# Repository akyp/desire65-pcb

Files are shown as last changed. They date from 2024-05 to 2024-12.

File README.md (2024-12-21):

# desire65-pcb
 
 Open-source 65% hotswap pcb. Could be useful for keyboard designers looking for a PCB for gasket or top-mounted boards.
  
 ## Features
 
 - [UDB (Unified DB)](https://unified-daughterboard.github.io) compatibility (JST-SH variant)
 - Hotswap
 - Underglow RGB LEDs
 - Header for in-switch Caps Lock LED (alternative firmware to use it as backlight to be provided)
 - RP2040 MCU
 - QMK/VIA/Vial firmware
 - Holes under 2u stabilizers to facilitate proper keycap installation on long-pole switches
 - Rounded tracks
 - [STEP file](./step/desire65-rounded.step) provided with all the components visible
 - Requires KiCad 8 to modify or produce production files
 - Font used: [Orbitron](https://fonts.google.com/specimen/Orbitron)
 
## Firmware
 - [QMK](https://config.qmk.fm/#/archerkeyboard/desire65/LAYOUT_65_ansi_blocker_tsangan_split_bs)
 - [VIA](https://www.caniusevia.com/docs/download_firmware)
 - [VIAL (with the Caps Lock footprint configured as QMK Backlighting instead)](https://github.com/akyp/desire65-pcb/releases/tag/v1.0_vial_bl)

## Supported Layout
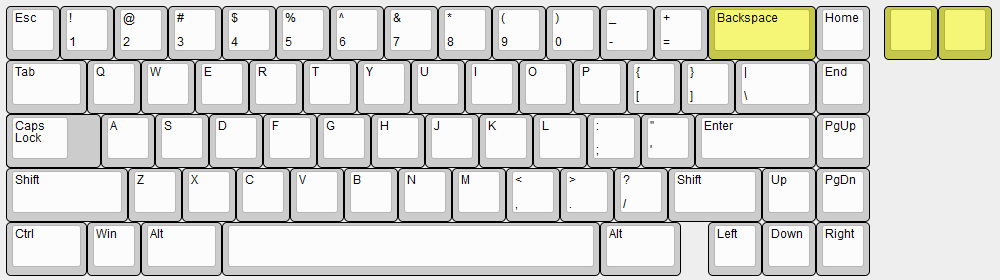
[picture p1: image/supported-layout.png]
Supported Layout


## Renders
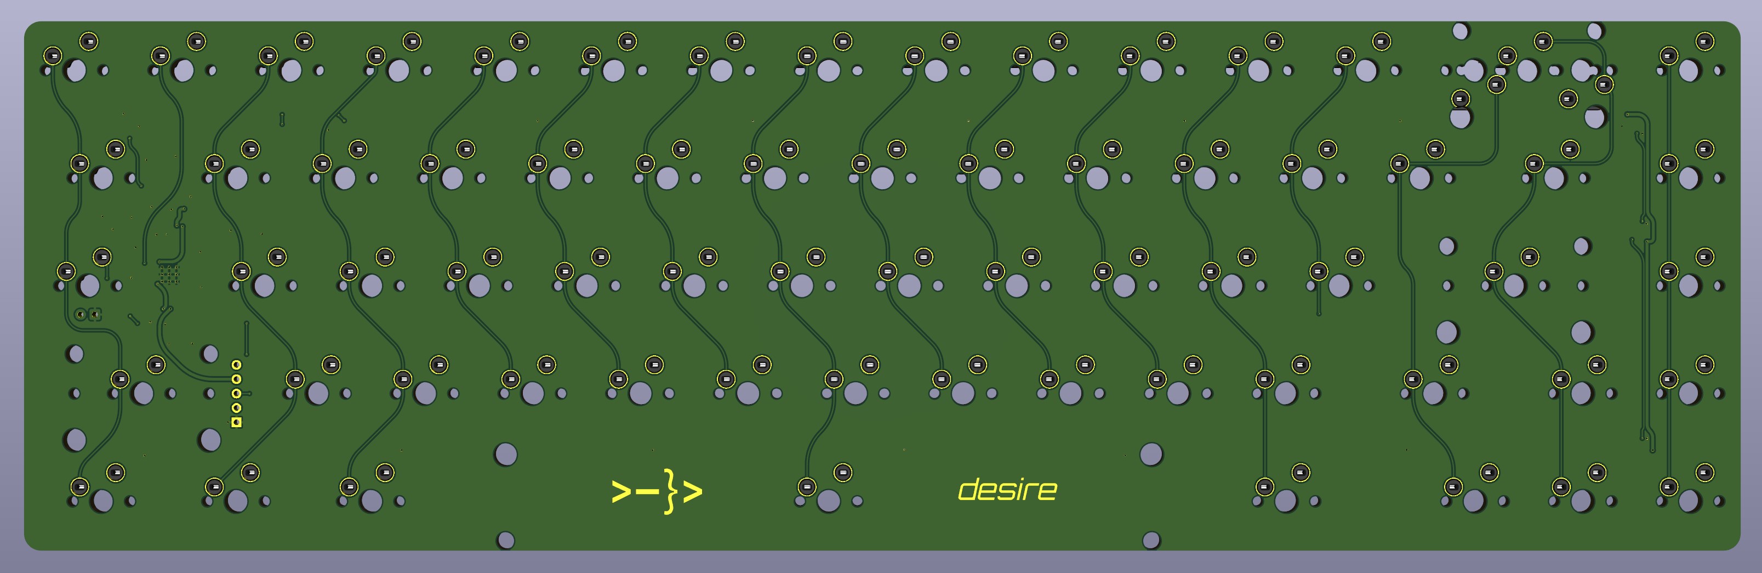
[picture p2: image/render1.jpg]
Render 1

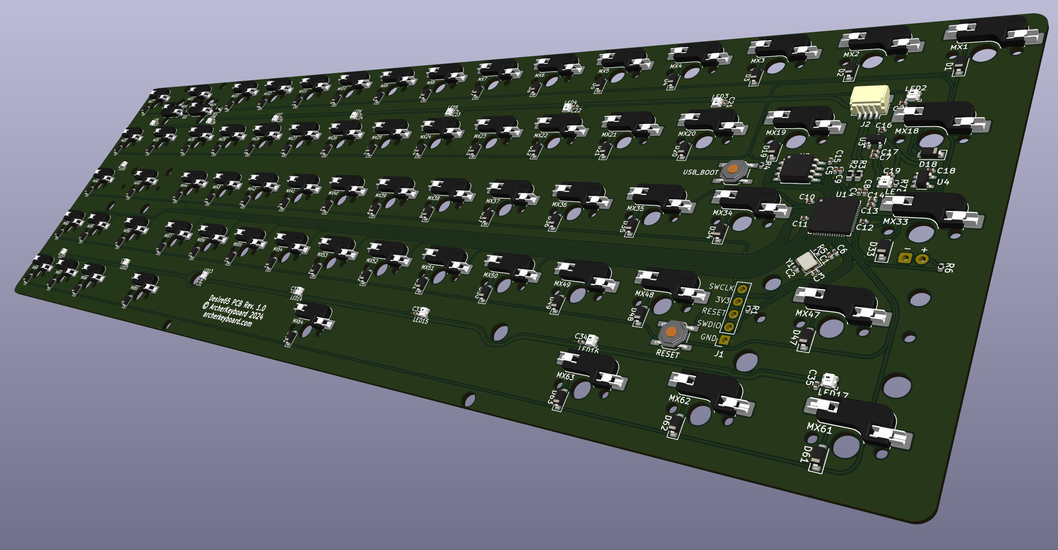
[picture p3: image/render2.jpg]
Render 2


## Prototype Photos
1.2mm PCB produced by JLCPCB
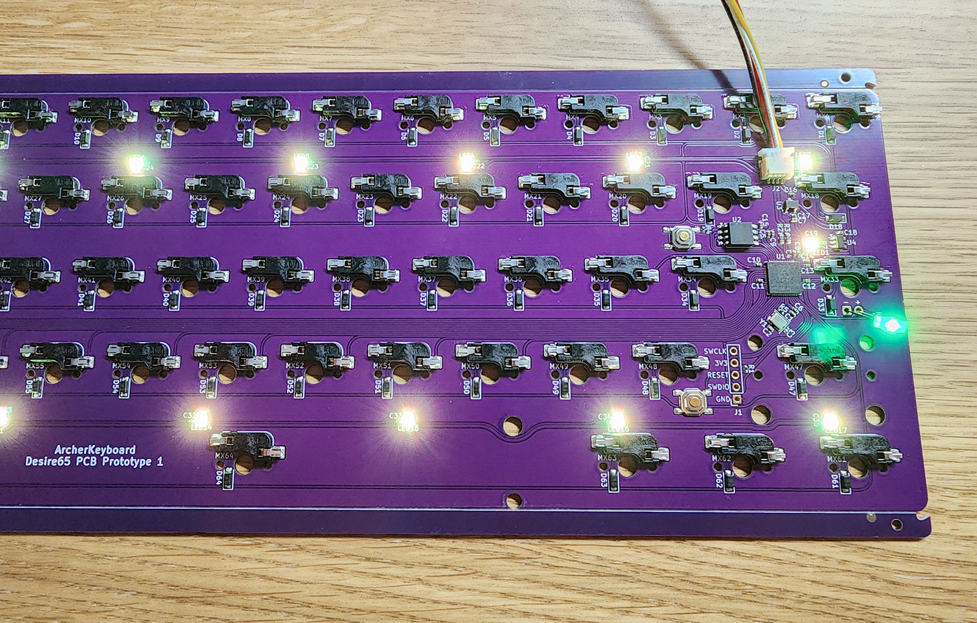
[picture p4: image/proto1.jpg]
Prototype Photo 1

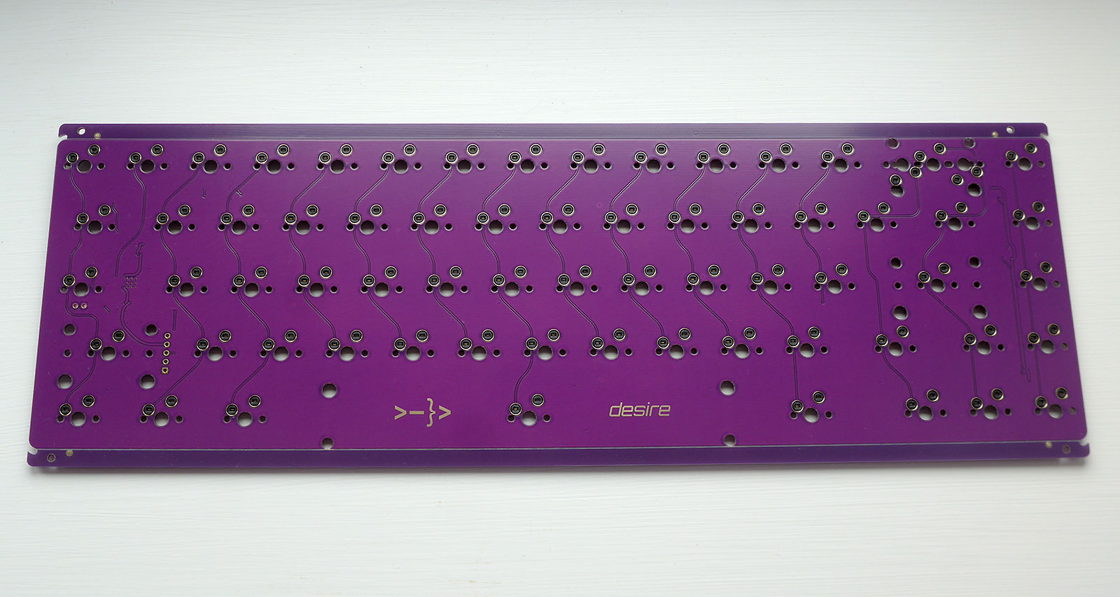
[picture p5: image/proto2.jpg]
Prototype Photo 2

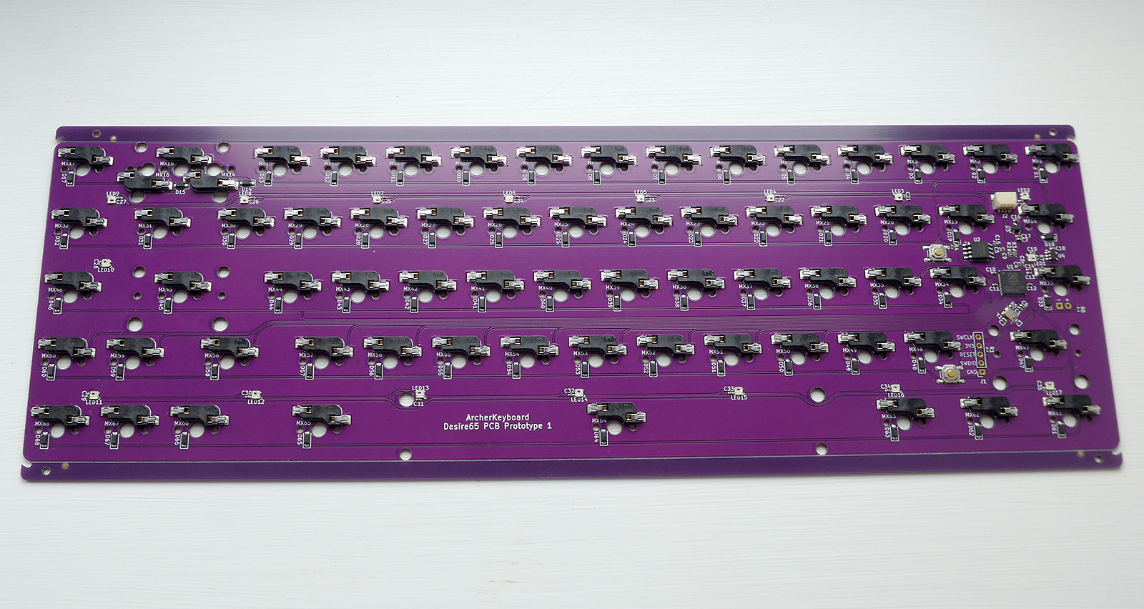
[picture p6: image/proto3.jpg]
Prototype Photo 3


## About the holes under 2u stabilizers
It is not easy to fully install a 2/2.25/2.75u keycap on the stabilizer stems when using a long-pole switch with reduced travel. Often one side will be inserted more than the other, causing rattle. The holes on the PCB allow the use of a spare 2u wire underneath to facilitate pushing the stabilizer stems fully into the keycap.
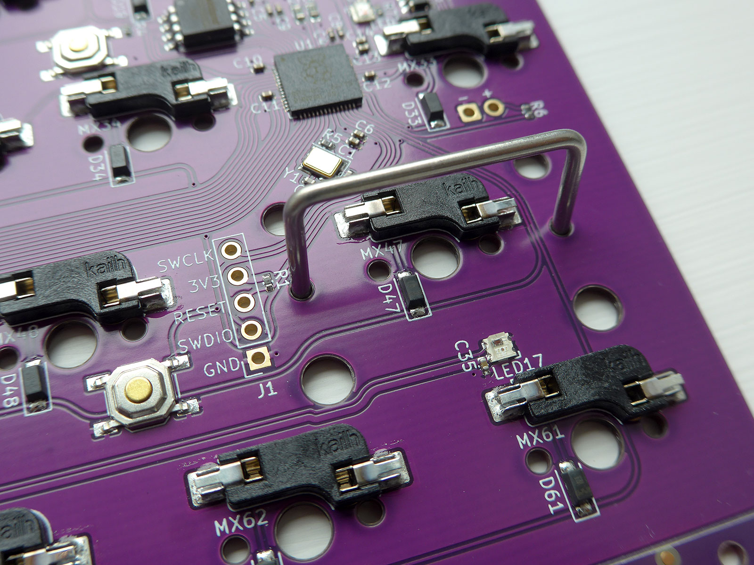
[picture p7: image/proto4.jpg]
Prototype Photo 4


## Plugins Used

 - [marbastlib](https://github.com/ebastler/marbastlib)
 - [Round Tracks](https://github.com/mitxela/kicad-round-tracks)

## If you want to modify the PCB

 - Fork this repo
 - Changes to component placement and tracks must be made to **desire65.kicad_pcb** rather than **desire65-rounded.kicad_pcb**
 - When you're done, use the Round Tracks plugin with **create a new file option** checked to generate a new **desire65-rounded.kicad_pcb**
 - Open it and manually fix track-to-track and track-to-pad clearances. Use DRC to find them.
 - Feel free to ignore the generated **desire65-rounded.kicad_pro**

## Thanks to

 - **Sleepdealr** for the [RP2040 Design Guide](https://github.com/Sleepdealr/RP2040-designguide)
 - **ebastler** for the super-useful [marbastlib](https://github.com/ebastler/marbastlib)
 - **zykrah** for [KiCad KLE Placer](https://github.com/zykrah/kicad-kle-placer) and [Firmware Scripts](https://github.com/zykrah/firmware-scripts)
 - **ai03** for the [PCB Designer Guide](https://wiki.ai03.com/books/pcb-design/chapter/pcb-designer-guide)
 - Folks on Keyboard Atelier Discord

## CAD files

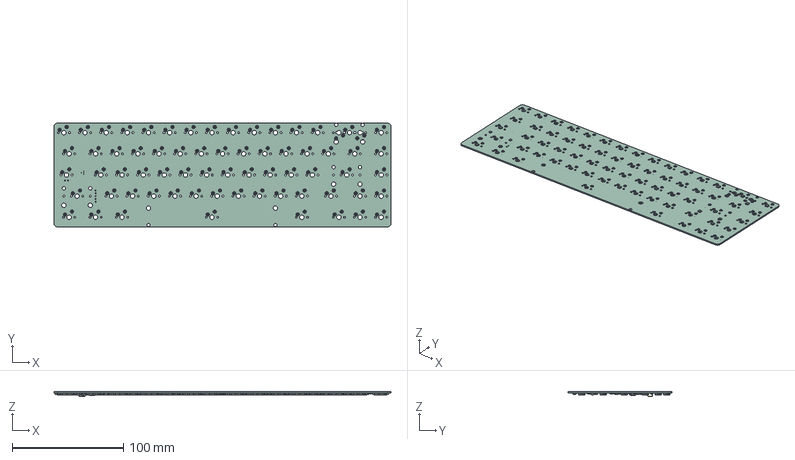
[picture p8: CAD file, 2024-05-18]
step/desire65-rounded.step
303.5 x 93.5 x 4.21 mm
D_SOD_123 x 67
Kailh Hotswap RightVersion v23 x 68
C_0402_1005Metric x 35
Crystal_SMD_3225-4Pin_3.2x2.5mm
SW_SPST_TL3342 x 2
LED_WS2812_2020 v3 x 17
R_0402_1005Metric x 5
R_0603_1608Metric x 2
SOT_23
SOT_23_5
SM04B-SRSS-TB(LF)(SN)
QFN-56-1EP_7x7mm_Pitch0.4mm
SOIC_8_5275x5275mm_P127mm
_autosave-desire65-rounded_PCB

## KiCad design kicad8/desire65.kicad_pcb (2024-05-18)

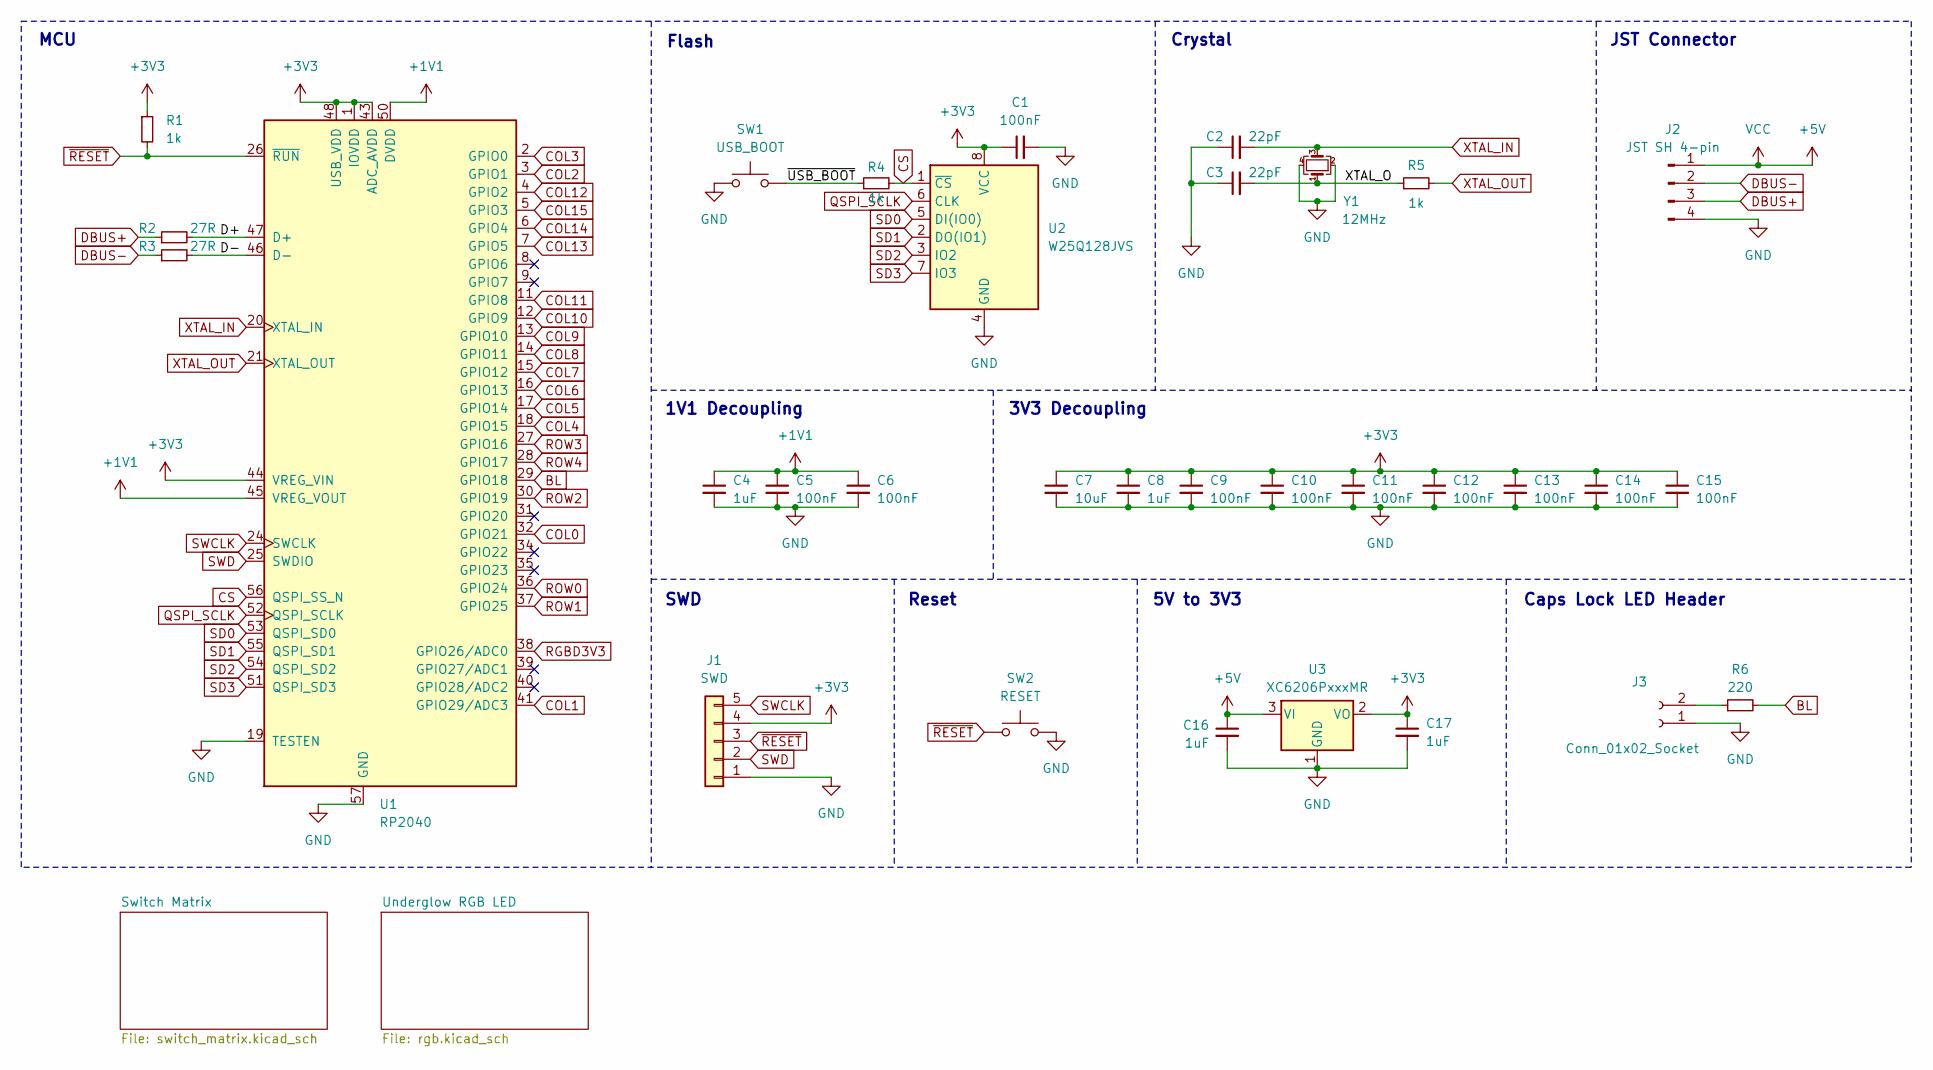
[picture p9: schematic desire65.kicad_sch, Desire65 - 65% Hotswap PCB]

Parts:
C1, C5, C6, C9, C10, C11, C12, C13, C14, C15: 100nF; C_0402_1005Metric; LCSC Part C1525
C2, C3: 22pF; C_0402_1005Metric; LCSC Part C1555
C4, C8, C16, C17: 1uF; C_0402_1005Metric; LCSC Part C52923
C7: 10uF; C_0402_1005Metric; LCSC Part C15525
J1: SWD; PinSocket_1x05_P2.54mm_Vertical; JLCPCB BOM 0
J2: JST SH 4-pin; JST_SH_SM04B-SRSS-TB_1x04-1MP_P1.00mm_Horizontal; LCSC Part C371571
J3: Conn_01x02_Socket; LED_MX_3mm; JLCPCB BOM 0
R1, R4, R5: 1k; R_0402_1005Metric; LCSC Part C11702
R2, R3: 27R; R_0603_1608Metric; LCSC Part C25190
R6: 220; R_0402_1005Metric; LCSC Part C25091
SW1: USB_BOOT; SW_SPST_TL3342
SW2: RESET; SW_SPST_TL3342
U1: RP2040; RP2040-QFN-56; LCSC Part C2040
U2: W25Q128JVS; SOIC-8_5.23x5.23mm_P1.27mm; LCSC Part C97521
U3: XC6206PxxxMR; SOT-23; LCSC Part C5446
Y1: 12MHz; Crystal_SMD_3225-4Pin_3.2x2.5mm; LCSC Part C9002

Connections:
+1V1: C4.1, C5.1, C6.1, U1.23 (DVDD), U1.45 (VREG_VOUT), U1.50 (DVDD)
+3V3: C1.1, C7.1, C8.1, C9.1, C10.1, C11.1, C12.1, C13.1, C14.1, C15.1, C17.1, J1.4, R1.1, U1.1 (IOVDD), U1.10 (IOVDD), U1.22 (IOVDD), U1.33 (IOVDD), U1.42 (IOVDD), U1.43 (ADC_AVDD), U1.44 (VREG_VIN), U1.48 (USB_VDD), U1.49 (IOVDD), U2.8 (VCC), U3.2 (VO)
+5V: C16.1, J2.1, U3.3 (VI); also elsewhere on the board
/D+: R2.2, U1.47 (D+)
/D-: R3.2, U1.46 (D-)
/XTAL_O: C3.2, R5.1, Y1.1
/~USB_BOOT: R4.1, SW1.2
BL: R6.2, U1.29 (GPIO18)
COL0: U1.32 (GPIO21); also elsewhere on the board
COL1: U1.41 (GPIO29/ADC3); also elsewhere on the board
COL2: U1.3 (GPIO1); also elsewhere on the board
COL3: U1.2 (GPIO0); also elsewhere on the board
COL4: U1.18 (GPIO15); also elsewhere on the board
COL5: U1.17 (GPIO14); also elsewhere on the board
COL6: U1.16 (GPIO13); also elsewhere on the board
COL7: U1.15 (GPIO12); also elsewhere on the board
COL8: U1.14 (GPIO11); also elsewhere on the board
COL9: U1.13 (GPIO10); also elsewhere on the board
COL10: U1.12 (GPIO9); also elsewhere on the board
COL11: U1.11 (GPIO8); also elsewhere on the board
COL12: U1.4 (GPIO2); also elsewhere on the board
COL13: U1.7 (GPIO5); also elsewhere on the board
COL14: U1.6 (GPIO4); also elsewhere on the board
COL15: U1.5 (GPIO3); also elsewhere on the board
CS: R4.2, U1.56 (QSPI_SS_N), U2.1 (~CS)
DBUS+: J2.3, R2.1
DBUS-: J2.2, R3.1
GND: C1.2, C2.1, C3.1, C4.2, C5.2, C6.2, C7.2, C8.2, C9.2, C10.2, C11.2, C12.2, C13.2, C14.2, C15.2, C16.2, C17.2, J1.1, J2.4, J3.1, SW1.1, SW2.2, U1.19 (TESTEN), U1.57 (GND), U2.4 (GND), U3.1 (GND), Y1.2, Y1.4; also elsewhere on the board
unnamed: J3.2, R6.1
QSPI_SCLK: U1.52 (QSPI_SCLK), U2.6 (CLK)
RGBD3V3: U1.38 (GPIO26/ADC0); also elsewhere on the board
ROW0: U1.36 (GPIO24); also elsewhere on the board
ROW1: U1.37 (GPIO25); also elsewhere on the board
ROW2: U1.30 (GPIO19); also elsewhere on the board
ROW3: U1.27 (GPIO16); also elsewhere on the board
ROW4: U1.28 (GPIO17); also elsewhere on the board
SD0: U1.53 (QSPI_SD0), U2.5 (DI(IO0))
SD1: U1.55 (QSPI_SD1), U2.2 (DO(IO1))
SD2: U1.54 (QSPI_SD2), U2.3 (IO2)
SD3: U1.51 (QSPI_SD3), U2.7 (IO3)
SWCLK: J1.5, U1.24 (SWCLK)
SWD: J1.2, U1.25 (SWDIO)
XTAL_IN: C2.2, U1.20 (XTAL_IN), Y1.3
XTAL_OUT: R5.2, U1.21 (XTAL_OUT)
~RESET: J1.3, R1.2, SW2.1, U1.26 (~RUN)

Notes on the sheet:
JST Connector
5V to 3V3
SWD
MCU
Caps Lock LED Header
1V1 Decoupling
Reset
Flash
Crystal
3V3 Decoupling

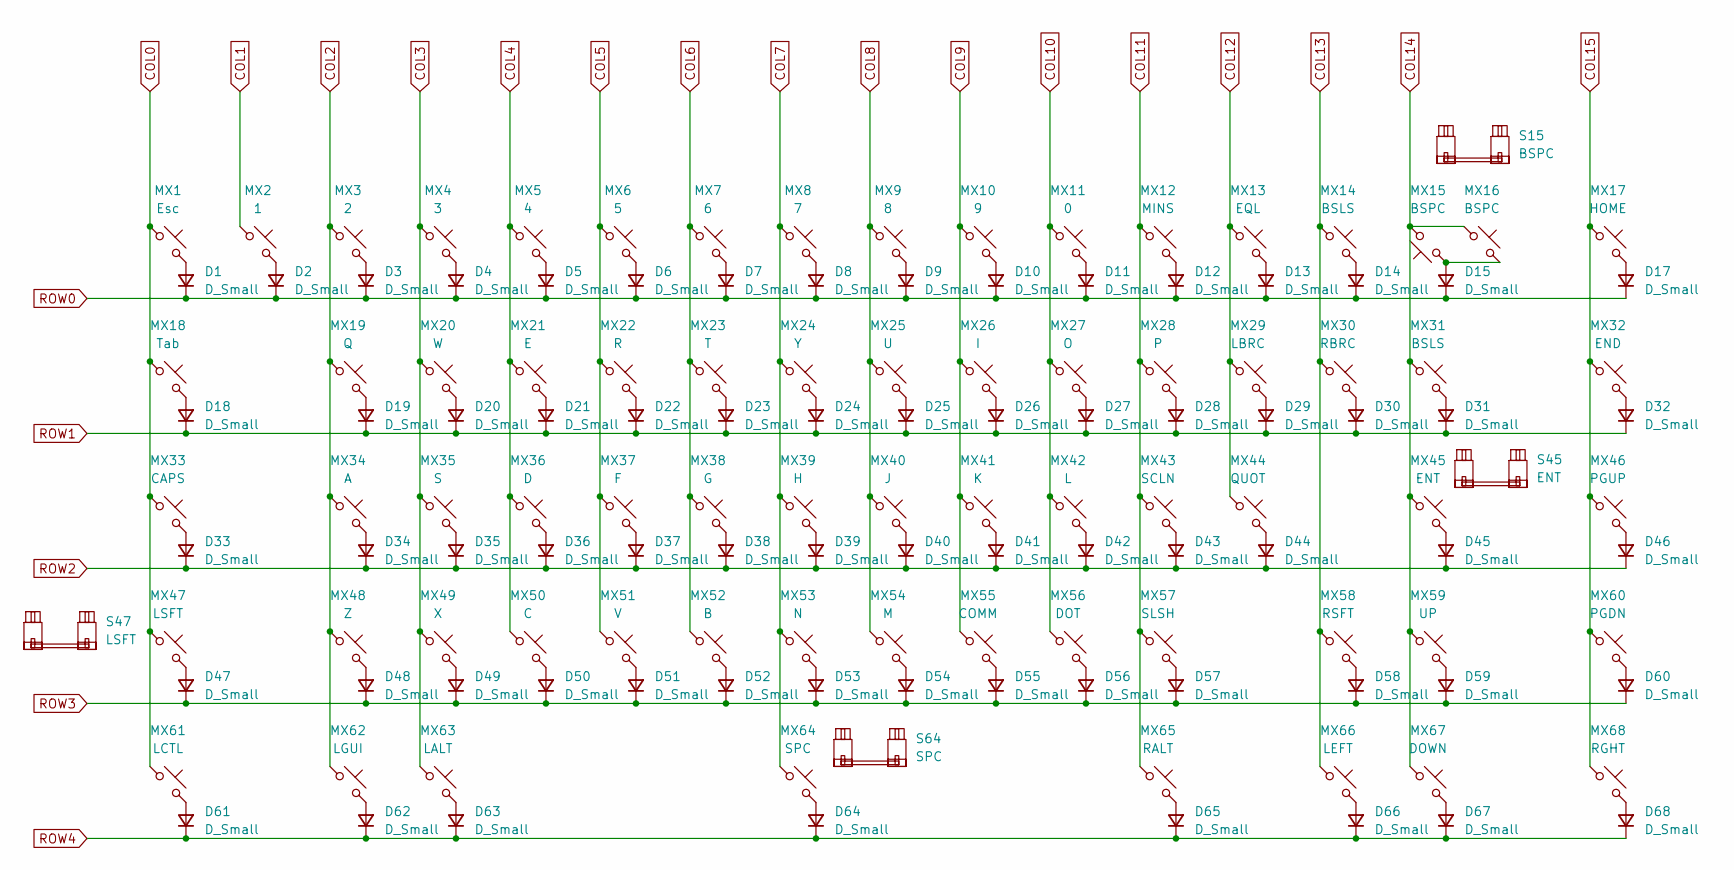
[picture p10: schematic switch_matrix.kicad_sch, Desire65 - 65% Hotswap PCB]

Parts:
D1, D2, D3, D4, D5, D6, D7, D8, D9, D10, D11, D12, D13, D14, D15, D17, D18, D19, D20, D21, D22, D23, D24, D25, D26, D27, D28, D29, D30, D31, D32, D33, D34, D35, D36, D37, D38, D39, D40, D41, D42, D43, D44, D45, D46, D47, D48, D49, D50, D51, D52, D53, D54, D55, D56, D57, D58, D59, D60, D61, D62, D63, D64, D65, D66, D67, D68: D_Small; D_SOD-123; LCSC Part C81598
MX1: Esc; SW_MX_HS_CPG151101S11_1u; LCSC Part C5156480
MX2: 1; SW_MX_HS_CPG151101S11_1u; LCSC Part C5156480
MX3: 2; SW_MX_HS_CPG151101S11_1u; LCSC Part C5156480
MX4: 3; SW_MX_HS_CPG151101S11_1u; LCSC Part C5156480
MX5: 4; SW_MX_HS_CPG151101S11_1u; LCSC Part C5156480
MX6: 5; SW_MX_HS_CPG151101S11_1u; LCSC Part C5156480
MX7: 6; SW_MX_HS_CPG151101S11_1u; LCSC Part C5156480
MX8: 7; SW_MX_HS_CPG151101S11_1u; LCSC Part C5156480
MX9: 8; SW_MX_HS_CPG151101S11_1u; LCSC Part C5156480
MX10: 9; SW_MX_HS_CPG151101S11_1u; LCSC Part C5156480
MX11: 0; SW_MX_HS_CPG151101S11_1u; LCSC Part C5156480
MX12: MINS; SW_MX_HS_CPG151101S11_1u; LCSC Part C5156480
MX13: EQL; SW_MX_HS_CPG151101S11_1u; LCSC Part C5156480
MX14: BSLS; SW_MX_HS_CPG151101S11_1u; LCSC Part C5156480
MX15, MX16: BSPC; SW_MX_HS_CPG151101S11_1u; LCSC Part C5156480
MX17: HOME; SW_MX_HS_CPG151101S11_1u; LCSC Part C5156480
MX18: Tab; SW_MX_HS_CPG151101S11_1.5u; LCSC Part C5156480
MX19: Q; SW_MX_HS_CPG151101S11_1u; LCSC Part C5156480
MX20: W; SW_MX_HS_CPG151101S11_1u; LCSC Part C5156480
MX21: E; SW_MX_HS_CPG151101S11_1u; LCSC Part C5156480
MX22: R; SW_MX_HS_CPG151101S11_1u; LCSC Part C5156480
MX23: T; SW_MX_HS_CPG151101S11_1u; LCSC Part C5156480
MX24: Y; SW_MX_HS_CPG151101S11_1u; LCSC Part C5156480
MX25: U; SW_MX_HS_CPG151101S11_1u; LCSC Part C5156480
MX26: I; SW_MX_HS_CPG151101S11_1u; LCSC Part C5156480
MX27: O; SW_MX_HS_CPG151101S11_1u; LCSC Part C5156480
MX28: P; SW_MX_HS_CPG151101S11_1u; LCSC Part C5156480
MX29: LBRC; SW_MX_HS_CPG151101S11_1u; LCSC Part C5156480
MX30: RBRC; SW_MX_HS_CPG151101S11_1u; LCSC Part C5156480
MX31: BSLS; SW_MX_HS_CPG151101S11_1.5u; LCSC Part C5156480
MX32: END; SW_MX_HS_CPG151101S11_1u; LCSC Part C5156480
MX33: CAPS; SW_MX_HS_CPG151101S11_1.75u_STP_1.25; LCSC Part C5156480
MX34: A; SW_MX_HS_CPG151101S11_1u; LCSC Part C5156480
MX35: S; SW_MX_HS_CPG151101S11_1u; LCSC Part C5156480
MX36: D; SW_MX_HS_CPG151101S11_1u; LCSC Part C5156480
MX37: F; SW_MX_HS_CPG151101S11_1u; LCSC Part C5156480
MX38: G; SW_MX_HS_CPG151101S11_1u; LCSC Part C5156480
MX39: H; SW_MX_HS_CPG151101S11_1u; LCSC Part C5156480
MX40: J; SW_MX_HS_CPG151101S11_1u; LCSC Part C5156480
MX41: K; SW_MX_HS_CPG151101S11_1u; LCSC Part C5156480
MX42: L; SW_MX_HS_CPG151101S11_1u; LCSC Part C5156480
MX43: SCLN; SW_MX_HS_CPG151101S11_1u; LCSC Part C5156480
MX44: QUOT; SW_MX_HS_CPG151101S11_1u; LCSC Part C5156480
MX45: ENT; SW_MX_HS_CPG151101S11_1u; LCSC Part C5156480
MX46: PGUP; SW_MX_HS_CPG151101S11_1u; LCSC Part C5156480
MX47: LSFT; SW_MX_HS_CPG151101S11_1u; LCSC Part C5156480
MX48: Z; SW_MX_HS_CPG151101S11_1u; LCSC Part C5156480
MX49: X; SW_MX_HS_CPG151101S11_1u; LCSC Part C5156480
MX50: C; SW_MX_HS_CPG151101S11_1u; LCSC Part C5156480
MX51: V; SW_MX_HS_CPG151101S11_1u; LCSC Part C5156480
MX52: B; SW_MX_HS_CPG151101S11_1u; LCSC Part C5156480
MX53: N; SW_MX_HS_CPG151101S11_1u; LCSC Part C5156480
MX54: M; SW_MX_HS_CPG151101S11_1u; LCSC Part C5156480
MX55: COMM; SW_MX_HS_CPG151101S11_1u; LCSC Part C5156480
MX56: DOT; SW_MX_HS_CPG151101S11_1u; LCSC Part C5156480
MX57: SLSH; SW_MX_HS_CPG151101S11_1u; LCSC Part C5156480
MX58: RSFT; SW_MX_HS_CPG151101S11_1.75u; LCSC Part C5156480
MX59: UP; SW_MX_HS_CPG151101S11_1u; LCSC Part C5156480
MX60: PGDN; SW_MX_HS_CPG151101S11_1u; LCSC Part C5156480
MX61: LCTL; SW_MX_HS_CPG151101S11_1.5u; LCSC Part C5156480
MX62: LGUI; SW_MX_HS_CPG151101S11_1u; LCSC Part C5156480
MX63: LALT; SW_MX_HS_CPG151101S11_1.5u; LCSC Part C5156480
MX64: SPC; SW_MX_HS_CPG151101S11_1u; LCSC Part C5156480
MX65: RALT; SW_MX_HS_CPG151101S11_1.5u; LCSC Part C5156480
MX66: LEFT; SW_MX_HS_CPG151101S11_1u; LCSC Part C5156480
MX67: DOWN; SW_MX_HS_CPG151101S11_1u; LCSC Part C5156480
MX68: RGHT; SW_MX_HS_CPG151101S11_1u; LCSC Part C5156480
S15: BSPC; STAB_MX_2u; JLCPCB BOM 0
S45: ENT; STAB_MX_2.25u; JLCPCB BOM 0
S47: LSFT; STAB_MX_2.25u; JLCPCB BOM 0
S64: SPC; STAB_MX_7u; JLCPCB BOM 0

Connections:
COL0: MX1.1, MX18.1, MX33.1, MX47.1, MX61.1; also elsewhere on the board
COL1: MX2.1; also elsewhere on the board
COL2: MX3.1, MX19.1, MX34.1, MX48.1, MX62.1; also elsewhere on the board
COL3: MX4.1, MX20.1, MX35.1, MX49.1, MX63.1; also elsewhere on the board
COL4: MX5.1, MX21.1, MX36.1, MX50.1; also elsewhere on the board
COL5: MX6.1, MX22.1, MX37.1, MX51.1; also elsewhere on the board
COL6: MX7.1, MX23.1, MX38.1, MX52.1; also elsewhere on the board
COL7: MX8.1, MX24.1, MX39.1, MX53.1, MX64.1; also elsewhere on the board
COL8: MX9.1, MX25.1, MX40.1, MX54.1; also elsewhere on the board
COL9: MX10.1, MX26.1, MX41.1, MX55.1; also elsewhere on the board
COL10: MX11.1, MX27.1, MX42.1, MX56.1; also elsewhere on the board
COL11: MX12.1, MX28.1, MX43.1, MX57.1, MX65.1; also elsewhere on the board
COL12: MX13.1, MX29.1, MX44.1; also elsewhere on the board
COL13: MX14.1, MX30.1, MX58.1, MX66.1; also elsewhere on the board
COL14: MX15.2, MX16.1, MX31.1, MX45.1, MX59.1, MX67.1; also elsewhere on the board
COL15: MX17.1, MX32.1, MX46.1, MX60.1, MX68.1; also elsewhere on the board
unnamed: D1.2 (A), MX1.2
unnamed: D2.2 (A), MX2.2
unnamed: D3.2 (A), MX3.2
unnamed: D4.2 (A), MX4.2
unnamed: D5.2 (A), MX5.2
unnamed: D6.2 (A), MX6.2
unnamed: D7.2 (A), MX7.2
unnamed: D8.2 (A), MX8.2
unnamed: D9.2 (A), MX9.2
unnamed: D10.2 (A), MX10.2
unnamed: D11.2 (A), MX11.2
unnamed: D12.2 (A), MX12.2
unnamed: D13.2 (A), MX13.2
unnamed: D14.2 (A), MX14.2
unnamed: D15.2 (A), MX15.1, MX16.2
unnamed: D17.2 (A), MX17.2
unnamed: D18.2 (A), MX18.2
unnamed: D19.2 (A), MX19.2
unnamed: D20.2 (A), MX20.2
unnamed: D21.2 (A), MX21.2
unnamed: D22.2 (A), MX22.2
unnamed: D23.2 (A), MX23.2
unnamed: D24.2 (A), MX24.2
unnamed: D25.2 (A), MX25.2
unnamed: D26.2 (A), MX26.2
unnamed: D27.2 (A), MX27.2
unnamed: D28.2 (A), MX28.2
unnamed: D29.2 (A), MX29.2
unnamed: D30.2 (A), MX30.2
unnamed: D31.2 (A), MX31.2
unnamed: D32.2 (A), MX32.2
unnamed: D33.2 (A), MX33.2
unnamed: D34.2 (A), MX34.2
unnamed: D35.2 (A), MX35.2
unnamed: D36.2 (A), MX36.2
unnamed: D37.2 (A), MX37.2
unnamed: D38.2 (A), MX38.2
unnamed: D39.2 (A), MX39.2
unnamed: D40.2 (A), MX40.2
unnamed: D41.2 (A), MX41.2
unnamed: D42.2 (A), MX42.2
unnamed: D43.2 (A), MX43.2
unnamed: D44.2 (A), MX44.2
unnamed: D45.2 (A), MX45.2
unnamed: D46.2 (A), MX46.2
unnamed: D47.2 (A), MX47.2
unnamed: D48.2 (A), MX48.2
unnamed: D49.2 (A), MX49.2
unnamed: D50.2 (A), MX50.2
unnamed: D51.2 (A), MX51.2
unnamed: D52.2 (A), MX52.2
unnamed: D53.2 (A), MX53.2
unnamed: D54.2 (A), MX54.2
unnamed: D55.2 (A), MX55.2
unnamed: D56.2 (A), MX56.2
unnamed: D57.2 (A), MX57.2
unnamed: D58.2 (A), MX58.2
unnamed: D59.2 (A), MX59.2
unnamed: D60.2 (A), MX60.2
unnamed: D61.2 (A), MX61.2
unnamed: D62.2 (A), MX62.2
unnamed: D63.2 (A), MX63.2
unnamed: D64.2 (A), MX64.2
unnamed: D65.2 (A), MX65.2
unnamed: D66.2 (A), MX66.2
unnamed: D67.2 (A), MX67.2
unnamed: D68.2 (A), MX68.2
ROW0: D1.1 (K), D2.1 (K), D3.1 (K), D4.1 (K), D5.1 (K), D6.1 (K), D7.1 (K), D8.1 (K), D9.1 (K), D10.1 (K), D11.1 (K), D12.1 (K), D13.1 (K), D14.1 (K), D15.1 (K), D17.1 (K); also elsewhere on the board
ROW1: D18.1 (K), D19.1 (K), D20.1 (K), D21.1 (K), D22.1 (K), D23.1 (K), D24.1 (K), D25.1 (K), D26.1 (K), D27.1 (K), D28.1 (K), D29.1 (K), D30.1 (K), D31.1 (K), D32.1 (K); also elsewhere on the board
ROW2: D33.1 (K), D34.1 (K), D35.1 (K), D36.1 (K), D37.1 (K), D38.1 (K), D39.1 (K), D40.1 (K), D41.1 (K), D42.1 (K), D43.1 (K), D44.1 (K), D45.1 (K), D46.1 (K); also elsewhere on the board
ROW3: D47.1 (K), D48.1 (K), D49.1 (K), D50.1 (K), D51.1 (K), D52.1 (K), D53.1 (K), D54.1 (K), D55.1 (K), D56.1 (K), D57.1 (K), D58.1 (K), D59.1 (K), D60.1 (K); also elsewhere on the board
ROW4: D61.1 (K), D62.1 (K), D63.1 (K), D64.1 (K), D65.1 (K), D66.1 (K), D67.1 (K), D68.1 (K); also elsewhere on the board

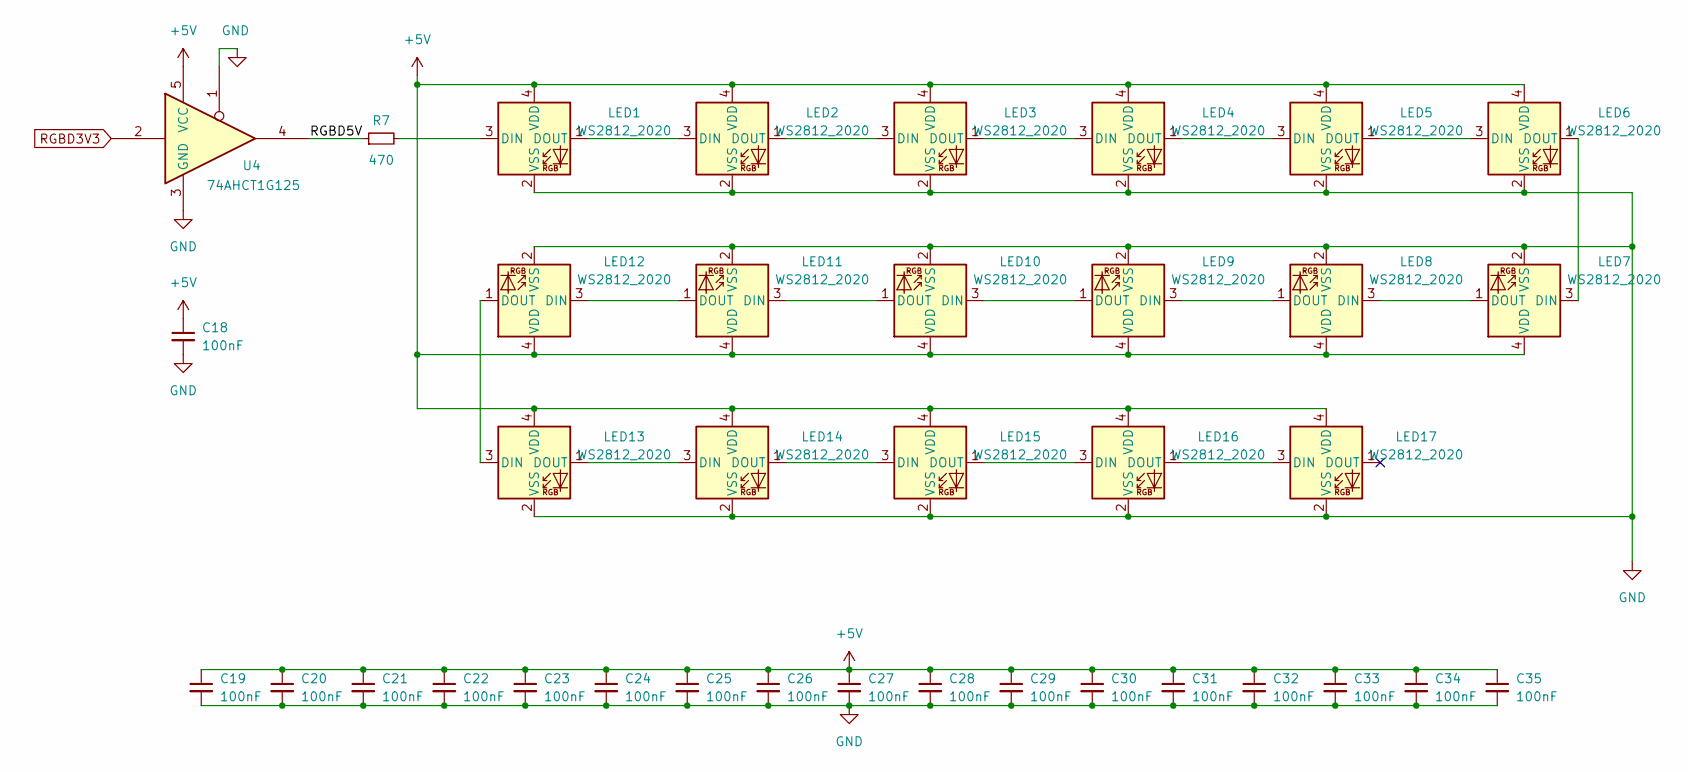
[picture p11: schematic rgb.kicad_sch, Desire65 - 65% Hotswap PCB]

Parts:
C18, C19, C20, C21, C22, C23, C24, C25, C26, C27, C28, C29, C30, C31, C32, C33, C34, C35: 100nF; C_0402_1005Metric; LCSC Part C1525
LED1, LED2, LED3, LED4, LED5, LED6, LED7, LED8, LED9, LED10, LED11, LED12, LED13, LED14, LED15, LED16, LED17: WS2812_2020; LED_WS2812_2020; LCSC Part C965555
R7: 470; R_0402_1005Metric; LCSC Part C25117
U4: 74AHCT1G125; SOT-23-5; LCSC Part C7484

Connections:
+5V: C18.1, C19.1, C20.1, C21.1, C22.1, C23.1, C24.1, C25.1, C26.1, C27.1, C28.1, C29.1, C30.1, C31.1, C32.1, C33.1, C34.1, C35.1, LED1.4 (VDD), LED2.4 (VDD), LED3.4 (VDD), LED4.4 (VDD), LED5.4 (VDD), LED6.4 (VDD), LED7.4 (VDD), LED8.4 (VDD), LED9.4 (VDD), LED10.4 (VDD), LED11.4 (VDD), LED12.4 (VDD), LED13.4 (VDD), LED14.4 (VDD), LED15.4 (VDD), LED16.4 (VDD), LED17.4 (VDD), U4.5 (VCC); also elsewhere on the board
/Underglow RGB LED/RGBD5V: R7.1, U4.4
GND: C18.2, C19.2, C20.2, C21.2, C22.2, C23.2, C24.2, C25.2, C26.2, C27.2, C28.2, C29.2, C30.2, C31.2, C32.2, C33.2, C34.2, C35.2, LED1.2 (VSS), LED2.2 (VSS), LED3.2 (VSS), LED4.2 (VSS), LED5.2 (VSS), LED6.2 (VSS), LED7.2 (VSS), LED8.2 (VSS), LED9.2 (VSS), LED10.2 (VSS), LED11.2 (VSS), LED12.2 (VSS), LED13.2 (VSS), LED14.2 (VSS), LED15.2 (VSS), LED16.2 (VSS), LED17.2 (VSS), U4.1, U4.3 (GND); also elsewhere on the board
unnamed: LED1.3 (DIN), R7.2
unnamed: LED1.1 (DOUT), LED2.3 (DIN)
unnamed: LED2.1 (DOUT), LED3.3 (DIN)
unnamed: LED3.1 (DOUT), LED4.3 (DIN)
unnamed: LED4.1 (DOUT), LED5.3 (DIN)
unnamed: LED5.1 (DOUT), LED6.3 (DIN)
unnamed: LED6.1 (DOUT), LED7.3 (DIN)
unnamed: LED7.1 (DOUT), LED8.3 (DIN)
unnamed: LED8.1 (DOUT), LED9.3 (DIN)
unnamed: LED9.1 (DOUT), LED10.3 (DIN)
unnamed: LED10.1 (DOUT), LED11.3 (DIN)
unnamed: LED11.1 (DOUT), LED12.3 (DIN)
unnamed: LED12.1 (DOUT), LED13.3 (DIN)
unnamed: LED13.1 (DOUT), LED14.3 (DIN)
unnamed: LED14.1 (DOUT), LED15.3 (DIN)
unnamed: LED15.1 (DOUT), LED16.3 (DIN)
unnamed: LED16.1 (DOUT), LED17.3 (DIN)
RGBD3V3: U4.2; also elsewhere on the board

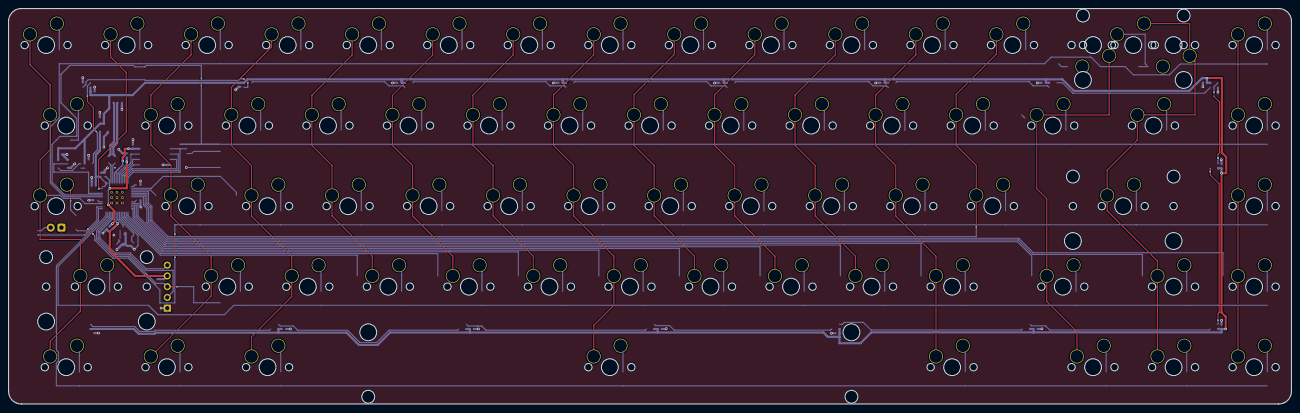
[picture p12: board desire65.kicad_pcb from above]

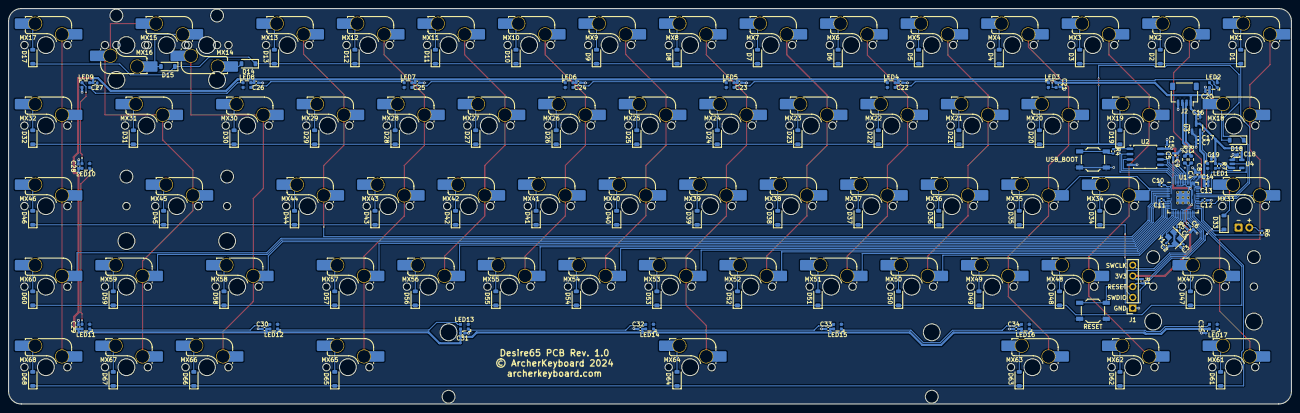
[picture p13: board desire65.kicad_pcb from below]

Board: 2 copper layers, 303.5 x 93.5 mm, 208 parts (203 on the bottom side), 130 nets.

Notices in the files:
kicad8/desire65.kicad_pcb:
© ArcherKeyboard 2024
